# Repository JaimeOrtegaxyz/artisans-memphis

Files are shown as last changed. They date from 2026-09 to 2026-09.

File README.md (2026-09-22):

# Memphis Artisan Keycaps

> **Untested 3D model:** These files have not been physically validated. I advise checking fit, switch clearance, tolerances, and print settings before relying on the models.

Four Memphis-inspired artisan keycaps with editable Blender models, overview drawings, and single-material STL prototypes.

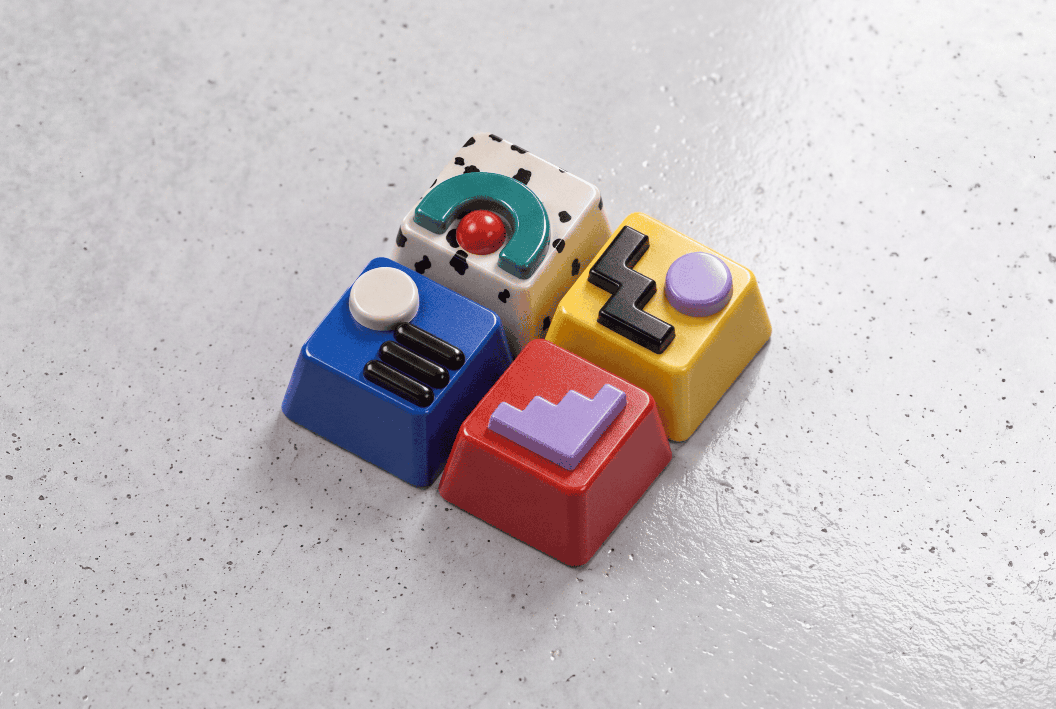
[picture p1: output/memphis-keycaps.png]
Memphis artisan keycaps


## The set

- **Arch / porcelain + teal** — concentric teal arch, orange hemisphere, and black patches wrapping around a cream base.
- **Zigzag / mustard + lilac** — a blocky black stepped beam beside a low lilac cylinder.
- **Disc / cobalt** — a cream disc and three rounded black rails reaching the deck’s edge.
- **Stairs / vermilion + lilac** — a compact, single-height staircase silhouette with room around its edges.

The **plain base is 9.8 mm tall**; the decoration sits above it. Each hollow base has a prototype MX-style socket, four permanent roof ribs, and a small insertion lead-in. This is a custom artisan profile informed by a GMK-based Cherry R1 reference—not an exact or certified GMK reproduction.

## Download and print

**Start with the plain-base fit test.** Check mounting, removal, full switch travel, neighboring-key clearance, and deck height on your keyboard before printing the decorated set.

| File | Purpose | Overall height |
| --- | --- | --- |
| [Base fit test](output/print/00_BASE_FIT_TEST.stl) | Undecorated base with socket and reinforcement | 9.8 mm |
| [Arch + dome](output/print/01_ARCH_DOME.stl) | Complete single-piece cap | 12.30 mm |
| [Zigzag + cylinder](output/print/02_ZIGZAG_CYLINDER.stl) | Complete single-piece cap | 11.45 mm |
| [Disc + rails](output/print/03_DISC_RAILS.stl) | Complete single-piece cap | 11.30 mm |
| [Stair silhouette](output/print/04_STAIR_SILHOUETTE.stl) | Complete single-piece cap | 11.45 mm |

### Full-color files

[output/color/](output/color/) holds the same five parts as **OBJ + MTL + PNG** for full-color printing (e.g. PolyJet). Every material color, including the procedural black porcelain patches, is baked into one 4096 px texture per part. Geometry and placement match the STLs: millimeters, Z up, skirt bottom at Z = 0. Keep each `.obj`, `.mtl` and `.png` together. [Color_Check.json](output/color/Color_Check.json) records the mesh audit, and [Color_Preview.png](output/color/Color_Preview.png) renders the textured parts for comparison with the hero render.

STL coordinates are **millimeters**, centered in X/Y with the skirt bottom at Z = 0. Import at **100% scale** and check for an 18 × 18 mm footprint. Each export is a boolean-joined, single-component closed mesh; [Print_Check.json](output/print/Print_Check.json) records the topology audit.

**These remain test-print prototypes, not production-ready keycaps.** Watertight geometry does not establish switch fit, material strength, shrinkage compensation, or print orientation. Never force a tight socket onto a switch. The STL files have **no colors or black stain pattern**: paint a single-material print, or use the full-color OBJ set. Choose supports and orientation in your slicer; the internal ribs are structural parts, not removable print supports.

## Open and edit

Use Blender **4.3.2** (the tested version) to open [Memphis_Artisans.blend](output/Memphis_Artisans.blend). Newer Blender versions may work but are not guaranteed.

```sh
git clone https://github.com/JaimeOrtegaxyz/artisans-memphis.git
cd artisans-memphis
```

Collections **01–04** contain one cap each; **05** is the studio. Colored parts and structural pieces remain separately editable in the source scene. The STL exporter joins them without modifying the `.blend`.

[Top view](output/Memphis_Top.png) · [Underside render](output/Memphis_Underside.png) · [Dimensions and fabrication notes](MODEL_NOTES.md)

## Overview drawings

Each 2400 × 1800 PNG includes top, front, right-side, and underside views. Dimensions distinguish the plain base from total height including decoration.

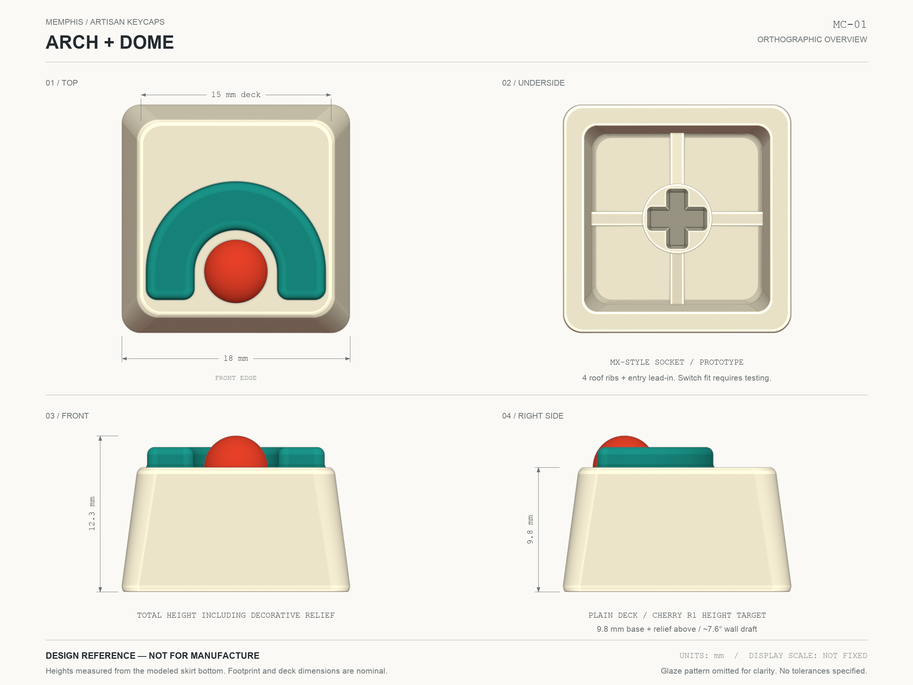
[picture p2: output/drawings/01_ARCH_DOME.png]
Example overview drawing: arch and dome keycap


[Arch + dome](output/drawings/01_ARCH_DOME.png) · [Zigzag + cylinder](output/drawings/02_ZIGZAG_CYLINDER.png) · [Disc + rails](output/drawings/03_DISC_RAILS.png) · [Stair silhouette](output/drawings/04_STAIR_SILHOUETTE.png)

These are **design references, not manufacturing drawings**. Glaze patterns are omitted; socket recesses use an illustrative darker tint. The images carry 300 DPI metadata, but their printed scale is not fixed.

## Dimensions

| Feature | Nominal value |
| --- | --- |
| Switch-center pitch | 19.05 mm |
| Skirt / deck | 18 × 18 / 15 × 15 mm |
| Plain base height | **9.8 mm**, excluding decoration |
| Main wall draft | Approximately 7.6° |
| Roof thickness | Approximately 1.85 mm |
| MX cross engagement | 4.20 mm long; 1.35 mm horizontal arm / 1.20 mm vertical arm; 4.20 mm deep |
| Socket boss | Ø5.5 mm |
| Entry lead-in | 0.30 mm at 45°; 0.10 mm arm-tip radii |
| Roof reinforcement | Four 1.10 mm nominal ribs |

The 9.8 mm height is a design target informed by owner measurements and [KeyV2’s GMK-based Cherry R1 definition](https://github.com/rsheldiii/KeyV2/blob/19f0d2faadd4949634c93f38d1a66869d29e8f43/src/key_profiles/cherry.scad). That reference includes stem-inset compensation; it is not a universal Cherry specification. See [MODEL_NOTES.md](MODEL_NOTES.md) for the mounting datums and fit caveats.

## Rebuild and verify

Requirements: Blender 4.3.2, Python 3.10+, and Pillow for drawing composition. No MCP is required. Install the drawing dependency in a virtual environment:

```sh
python3 -m venv .venv
. .venv/bin/activate
python -m pip install -r requirements.txt
```

With `blender` on your PATH:

```sh
blender -b --python build_memphis.py
blender -b output/Memphis_Artisans.blend --python validate_memphis.py
blender -b output/Memphis_Artisans.blend --python render_drawings.py
python compose_drawings.py
blender -b output/Memphis_Artisans.blend --python export_prints.py
blender -b output/Memphis_Artisans.blend --python export_color.py
python -m unittest discover -s tests -v
```

On macOS, substitute `/Applications/Blender.app/Contents/MacOS/Blender` for `blender`. On a headless Linux machine, run the drawing-render command under `xvfb-run -a` with Mesa/OpenGL available. Use `MEMPHIS_DRAFT=1 blender -b --python build_memphis.py` for faster 900 px preview renders.

**Rebuilding replaces generated outputs. Save manual edits elsewhere first.** Expected results are one editable scene, three renders, four drawing sheets, five STLs, five textured OBJ sets, and geometry/print/color audit reports. Geometry checks do not simulate switch travel or material strength.

## Project files

- `build_memphis.py` — model, materials, and render generator.
- `render_drawings.py` / `compose_drawings.py` — orthographic views and drawing sheets.
- `export_prints.py` — joined STL exports and print-mesh audit.
- `export_color.py` — joined full-color OBJ + MTL + PNG exports, texture bake, and audit.
- `validate_memphis.py` / `tests/` — component, dimension, and release-asset checks.
- `output/` — Blender scene and renders; `drawings/`, `print/` and `color/` contain the downloadable sheets and STLs.
- [Creative brief](artisans-memphis-creative-brief.md) · [Visual reference](artisans-memphis-render.png) · [Technical notes](MODEL_NOTES.md).

## Contributing and license

See [CONTRIBUTING](.github/CONTRIBUTING.md) for setup, validation, and fit-test reporting.

[MIT License](LICENSE). External tools, dependencies, and reference sources are documented in [THIRD_PARTY.md](.github/THIRD_PARTY.md). No affiliation with or endorsement by Cherry or GMK is implied.

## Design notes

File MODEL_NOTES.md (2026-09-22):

# Memphis / model and fabrication notes

## Dimensions and mounting datums

Model coordinates are millimeters. Blender's metric unit scale is 0.001. The 18 × 18 mm skirts sit on a 19.05 mm switch-center pitch, tapering to 15 × 15 mm flat decks. Main exterior wall draft is approximately 7.6°.

The source scene's skirt bottom is Z = 0.25 mm and plain deck is Z = 10.05 mm: **9.8 mm of base height before decoration**. STL exports translate the skirt bottom to Z = 0 without scaling.

| Cap | Plain base | Total including relief |
| --- | --- | --- |
| Arch + dome | 9.8 mm | 12.30 mm |
| Zigzag + cylinder | 9.8 mm | 11.45 mm |
| Disc + rails | 9.8 mm | 11.30 mm |
| Stair silhouette | 9.8 mm | 11.45 mm |

### Cherry R1 reference

The target is informed by the owner's roughly 9–10 mm measurements and [KeyV2's GMK-based Cherry profile](https://github.com/rsheldiii/KeyV2/blob/19f0d2faadd4949634c93f38d1a66869d29e8f43/src/key_profiles/cherry.scad). That source defines R1 depth as `9.8 - extra_stem_inset_height + extra_height`, with `extra_stem_inset_height = max(0.6 - stem_inset, 0)`. Its default compensation can reduce the depth to 9.2 mm. Dish, tilt, row labels, and mounting conventions matter; **9.8 mm is our chosen physical flat-deck height, not a universal manufacturer specification**.

[Keycaps.info](https://www.keycaps.info/) is useful for comparing row silhouettes, not for manufacturing dimensions. The artisans deliberately retain a wide, flat deck instead of copying a Cherry dish or tilted top. Actual alignment on the owner's keyboard must be tested.

## Relief geometry

- **Arch:** the 5 mm hemisphere and curved arch share XY center (0, -4.15). Inner/outer radii are 3.35/7 mm, producing a nominal 0.85 mm radial gap in plan and a 3.65 mm band. Short straight legs extend 2.15 mm below the arc centerline. Rounded terminals reach Y = -6.3 mm, approximately -6.42 mm including the glazed foot. The dome reaches Y = -6.65 mm. Relief is 1.6 mm; the dome rises 2.5 mm above the deck.
- **Porcelain patches:** a warped 3D Voronoi material creates flush black patches across the deck, shoulders, and exterior walls. The cavity and socket stay cream. This is a material effect, not mesh geometry, and is absent from STL.
- **Zigzag:** 2.85 mm-wide beam, 1.55 mm relief, 0.28 mm inside/outside plan radii, and an independent 0.45 mm shoulder roll. Lilac cylinder diameter is 6.9 mm, centered at (3.45, 2.6). Nominal sharp-corner-to-circle clearance is about 0.96 mm; fillets alter local clearances.
- **Disc and rails:** 7.1 mm disc centered at (-3.8, 2.45), almost touching the first rail. Three 8.3 × 2.35 mm pill-shaped rails reach the deck's right edge, with their lower halves buried in the roof.
- **Stairs:** a 10.5 × 10.5 mm stair-shaped outline, centered within nominal 2.25 mm margins. Its top is one plane at Z = 11.70 mm, 1.65 mm above the deck. Plan radii are 0.28 mm; shoulder roll is 0.45 mm.

Rounded motifs use broad 0.6 mm shoulder rolls. Glazed relief has a subtle 0.12 mm flared foot. Colored parts remain separate in the editable scene; these visual junctions are not engineered press-fit inlays.

## Socket and structural ribs

- Open underside, tapered cavity, approximately 1.85 mm roof.
- Centered 5.5 mm-diameter boss. In source-scene coordinates, mouth Z = 0.4 mm and seating stop Z = 4.6 mm.
- The cross is 4.20 mm long with separately tuned arms: **1.35 mm horizontal (X) arm, 1.20 mm vertical (Y) arm**, 4.20 mm deep. Measured MX-style stems are roughly 1.25–1.32 mm (X) and 1.05–1.10 mm (Y), about 4.0 mm long and 3.6–3.8 mm tall, so the stem never reaches the slot's ceiling and the boss rests on the slider. Arm tips have 0.10 mm radii to reduce crack-starting corners.
- A 0.30 mm / 45° entry chamfer eases insertion.
- These values are set up for a single untested full-color resin (PolyJet-type) order. Support material left in the blind slot tightens it, so both arms carry more clearance than Cherry's own interference-fit socket (4.1 × 1.17 mm, Ø5.6 boss). At bottom-out the boss dips roughly 0.2–0.4 mm into the switch housing opening. Ø5.5 matches common open-source caps and keeps margin under the ~5.8 mm limit.
- Socket parameters live at the top of `build_memphis.py` (`CROSS_*`, `SOCKET_DEPTH`, `LEAD_IN`, `BOSS_D`).
- Four 1.10 mm nominal-width radial ribs tie the boss into the roof and inner walls. Lower edges slope upward toward the walls; their lowest nominal Z is approximately 6.05 mm. Small 0.14 mm radii soften the braces.
- The ribs are permanent structural geometry, **not removable slicer supports**. They intentionally occupy the upper cavity to leave the lower housing space open.

These dimensions have not been physically validated for fit, full travel, fatigue, or strength. Test against the exact switch and printing/casting process.

## Printing and validation

`output/print/` contains four complete single-material caps and `00_BASE_FIT_TEST.stl`. The fit-test piece uses the same shell, socket, and reinforcement without decorative relief.

The exporter evaluates modifiers, boolean-unions the pieces, triangulates, and checks that each STL has one connected component, no non-manifold edges, no degenerate triangles, positive signed volume, and a skirt bottom at Z = 0. `Print_Check.json` records those results. `Geometry_Check.json` audits the separate source components and verifies base/socket dimensions and rib counts. Neither audit proves physical fit or successful printing.

1. Print the plain-base test first, using your intended material and calibration. Check that it mounts and removes without force.
2. Test the full switch stroke. Pay particular attention to housing contact with ribs, skirt clearance, and neighboring caps. Compare the plain deck—not the ornaments—to your keyboard's key heights.
3. Tune socket dimensions for the switch, printer accuracy, resin shrinkage, and curing. Use fine-detail printing suitable for small MX recesses. Avoid blindly scaling the whole cap: that also changes its footprint and height.
4. Choose orientation and temporary supports in the slicer. Protect the socket opening and top finish; ensure uncured resin can drain from the open cavity. Follow the resin/printer manufacturer's handling and curing instructions.
5. STL does not preserve colors or procedural patches. Paint a single-material print, or send the baked OBJ + MTL + PNG set in `output/color/` to a full-color printer. A press-fit colored assembly needs its own pockets, alignment features, and clearances.
6. If editing the model, regenerate exports and audit them again. Do not export the studio or mistake the editable overlapping parts for the already-joined print meshes.

## Files and regeneration

- `output/Memphis_Artisans.blend` — editable model, resin materials, camera, and studio.
- `output/Memphis_Artisans.png`, `Memphis_Top.png`, `Memphis_Underside.png` — three views.
- `output/drawings/` — four non-toleranced overview sheets and view metadata.
- `output/print/` — five joined STL prototypes and print audit.
- `build_memphis.py` — regenerates the scene and renders.
- `render_drawings.py` / `compose_drawings.py` — regenerate drawing sheets without saving changes to the source model.
- `export_prints.py` — regenerates joined print meshes without modifying the source model.
- `export_color.py` — regenerates the full-color OBJ + MTL + PNG set (baked textures) without modifying the source model.
- `output/color/` — five textured OBJ sets, color audit, and preview render.

See the [README](README.md) for complete setup and validation commands. Regeneration overwrites outputs; save manual work elsewhere first.

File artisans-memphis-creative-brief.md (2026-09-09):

# Memphis Artisan Keycap Set

## Creative premise

This is a coordinated set of four sculptural artisan keycaps for the keyboard's isolated 2×2 navigation cluster. Together they form a tiny Memphis-inspired installation: bold primary and secondary colors, playful geometric relief, deliberate asymmetry, and a slightly toy-like personality refined by clean construction and a glossy finish.

The set should feel like four related objects rather than four copies. Each keycap has its own composition, but they share the same visual vocabulary: rounded solids, architectural steps and arches, black graphic accents, and a restrained palette drawn from the keyboard's green, red, blue, yellow, and lavender details.

The original navigation legends are intentionally absent. These are decorative objects first, occupying a visually separate part of the board where their identity can come from form rather than text.

## The four keycaps

### 1. Arch and dome — upper left

An ivory or warm-cream base with irregular black patches wrapping onto its sides. A thick, low teal arch with short terminals frames a glossy red-orange hemisphere, concentric with the curved crown. The composition suggests a doorway, rainbow, or abstract face without resolving into any one symbol. It is the lightest cap in the set and acts as a visual bridge back to the keyboard's ivory alphanumeric keys.

### 2. Zigzag and violet cylinder — upper right

A saturated mustard-yellow base supports a chunky black stepped zigzag, like a tiny lightning bolt or bent architectural beam. A low lavender-violet cylinder sits near the upper-right corner, close to the zigzag. The tension between the dark angular shape and soft round disc gives this cap its character.

### 3. Disc and rails — lower left

A deep cobalt-blue base carries a raised warm-cream disc toward one side, balanced by three short parallel black rails. It can read as an abstract control panel, musical notation, or a sun beside horizontal shadows. This is the most graphic and restrained member of the group.

### 4. Lavender staircase — lower right

A vivid red-orange base holds a lavender stair-shaped silhouette centered on the surface. Its top is a single plane; the diagonal rise is in the outline, not in physical step heights. Small, consistent corner radii keep it architectural and blocky. This cap has the strongest sense of upward movement and completes the set with a clear sculptural silhouette.

## Shared form language

- Use visibly raised, tactile relief rather than printed graphics.
- Favor softened edges and friendly radii; nothing should feel sharp or aggressive.
- Let the geometry remain crisp and intentional, with enough negative space for each composition to read at keycap scale.
- Keep the four bases different in color but consistent in profile, gloss, and overall visual weight.
- Treat black as a precise graphic accent, not a dominant base color.
- Repeat lavender sparingly so the artisans relate to the keyboard chassis.
- The set should feel playful, collectible, and designed—not chaotic or novelty-driven.

## Material impression

The render suggests opaque cast resin or carefully finished multi-part resin pieces. A polished satin-to-gloss surface would suit the colorful toy-object quality, while slight translucency could be reserved for the small spherical elements. The terrazzo speckles on the cream cap may be embedded flecks or painted inclusions. Exact fabrication methods and engineering constraints can be decided during technical development.

## Relationship to the keyboard

The artisans concentrate complexity in the isolated upper-right cluster while leaving the main typing field calm. Their palette echoes the colored modifier keys without matching them mechanically: cobalt connects to Alt, red-orange to Control, teal/green to Shift, yellow to the rhombus keys, and lavender to the chassis. This makes the board feel composed as a whole while allowing the artisan block to be its expressive focal point.

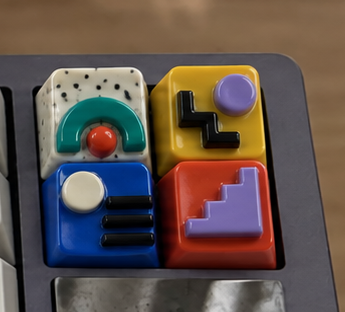
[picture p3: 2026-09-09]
artisans-memphis-render.png

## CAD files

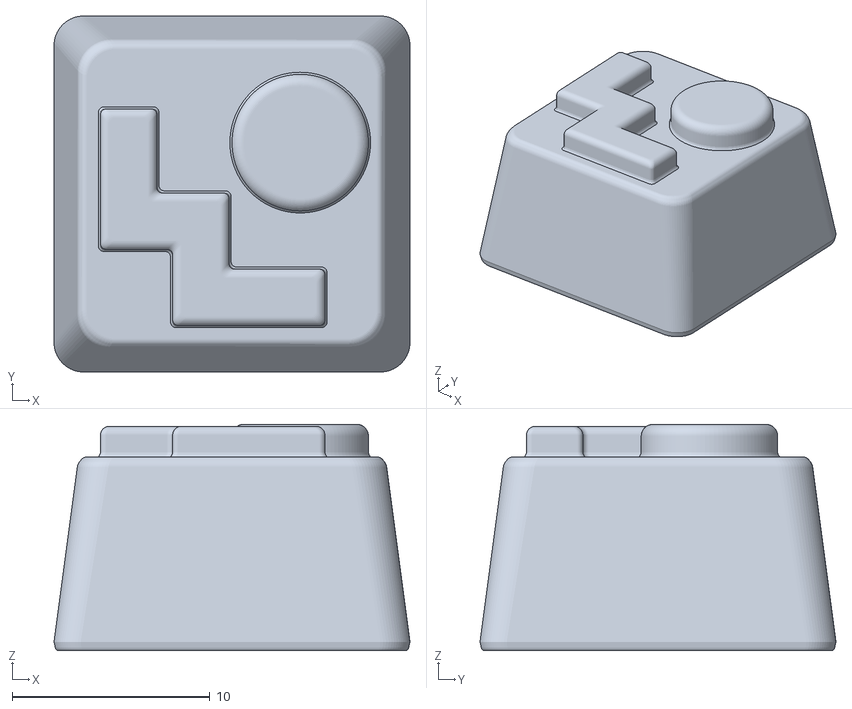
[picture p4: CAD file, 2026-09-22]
output/color/02_ZIGZAG_CYLINDER.obj
18.0 x 18.0 x 11.4

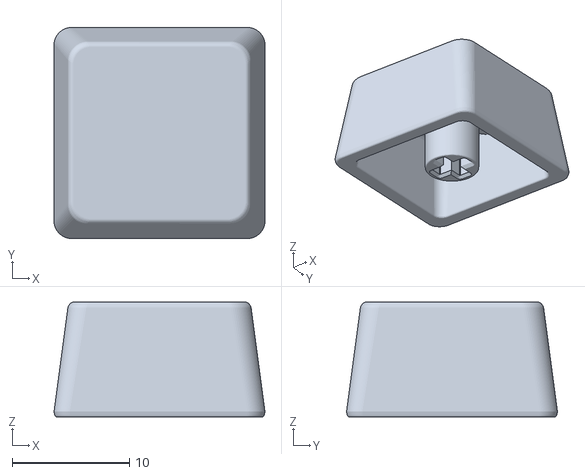
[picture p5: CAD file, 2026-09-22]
output/print/00_BASE_FIT_TEST.stl
18.0 x 18.0 x 9.80

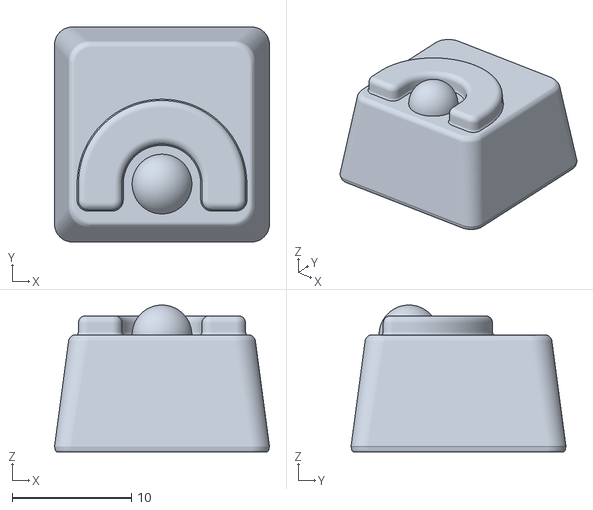
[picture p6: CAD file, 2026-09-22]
output/color/01_ARCH_DOME.obj
18.0 x 18.0 x 12.3

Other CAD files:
output/print/02_ZIGZAG_CYLINDER.stl
output/color/03_DISC_RAILS.obj
output/print/04_STAIR_SILHOUETTE.stl
output/color/04_STAIR_SILHOUETTE.obj
output/print/03_DISC_RAILS.stl
output/color/00_BASE_FIT_TEST.obj
output/print/01_ARCH_DOME.stl
output/Memphis_Artisans.blend

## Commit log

2026-09-09 Initial Memphis artisan keycap models, renders, and documentation
    [Memphis_Artisans.blend]
2026-09-09 Rev 04: raise plain decks to 9.8mm and reinforce MX sockets
    [Memphis_Artisans.blend]
2026-09-09 Prepare public prototype pack with STLs, current docs, and build checks
    [00_BASE_FIT_TEST.stl, 01_ARCH_DOME.stl, 02_ZIGZAG_CYLINDER.stl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]
2026-09-22 Retune MX socket for resin printing
    Separate X/Y arm widths (1.35/1.20), 4.2 mm depth, Ø5.5 boss,
    0.3 mm lead-in and rounded arm tips; validator measures each.
    Claude-Session: https://claude.ai/code/session_01WECezuvJGcuGvkp95jkFJ7
    [00_BASE_FIT_TEST.stl, 01_ARCH_DOME.stl, 02_ZIGZAG_CYLINDER.stl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]
2026-09-22 Add full-color OBJ export with baked textures
    OBJ + MTL + PNG per part for full-color (PolyJet) printing;
    porcelain stains baked from the procedural material.
    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
    [00_BASE_FIT_TEST.obj, 01_ARCH_DOME.obj, 02_ZIGZAG_CYLINDER.obj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]
2026-09-23 Give Dalmatian stains hard, crisp edges
    Constant color ramp and smooth noise replace the soft EASE falloff that
    smeared where the pattern stretched; bake with a narrow pixel filter.
    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
2026-09-23 Clear stains from the arch's inner pocket
    Drop whole stains centered within 2.7 mm of the dome so it sits on clean
    porcelain; regenerate renders and full-color textures.
    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
    [Memphis_Artisans.blend]
